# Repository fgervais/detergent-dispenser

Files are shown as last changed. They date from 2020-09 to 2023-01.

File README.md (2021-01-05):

# Detergent Dispenser

HE laundry detergent is quite concentrated and front loading washing machines
use really little water. With those two factors put together, it's really easy
to put too much detergent and so soap will be left even after the rinse cycle.

This project aim to automate the dispensing of a precise amount of detergent.

## Board

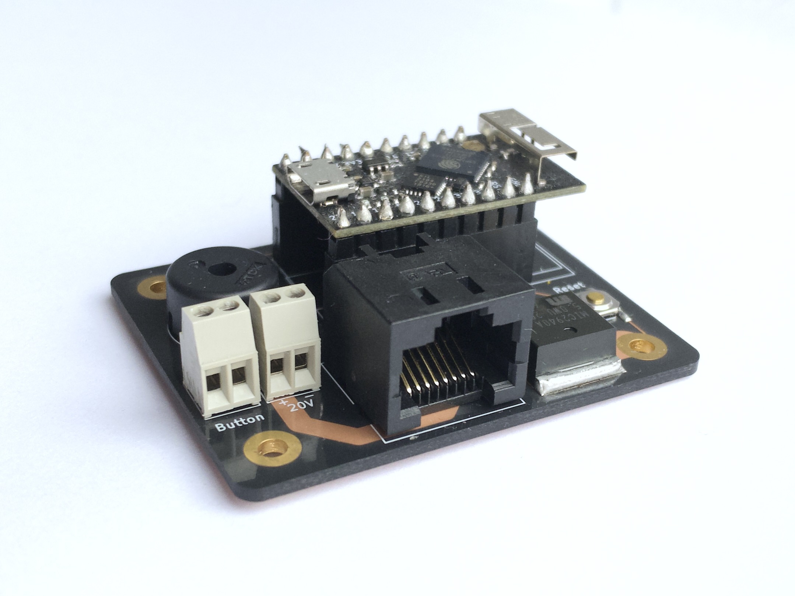
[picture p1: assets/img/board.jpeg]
Motherboard


## Assembled Unit

After holding the button for 1 seconds, the pump will dispense 7.5ml of
detergent. This has been empirically determined to be the required amount
for a small load on our dishwasher using our usual soap.

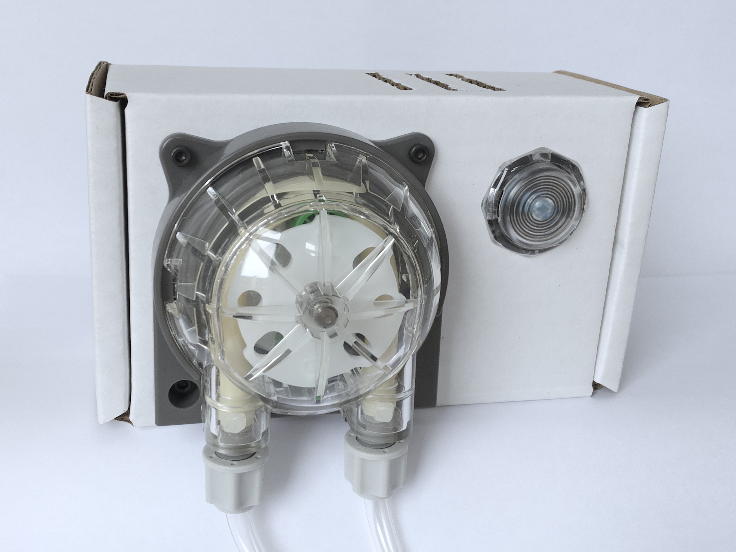
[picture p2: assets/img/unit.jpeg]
Assembled


## Installed

The pump feeds directly from the bottle.

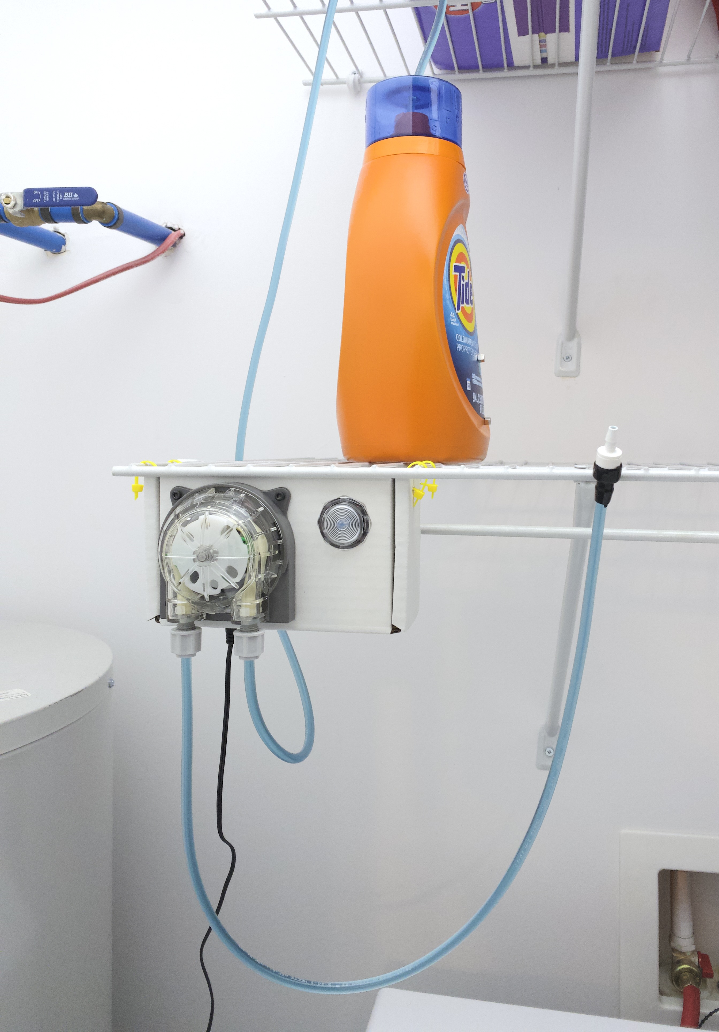
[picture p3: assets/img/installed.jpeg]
Installed


### Resource Efficiency

The bottle in this picture is rated for 44 loads but with the proper quantity determined for our specific case along with precise dispensing, we will get over 250 loads from this bottle.

(272 small loads of 7.5ml)

## Control App (Blynk)

The app shows when a dispense occurred and keep a global count since last
manual reset. It is also possible to start a dispense from the app.

All controls are locked by default and need to get unlocked through the
lock/unlock button. Once unlocked, only a single action is allowed before
controls are locked again automatically. This is to prevent unwanted counter reset or dispense.

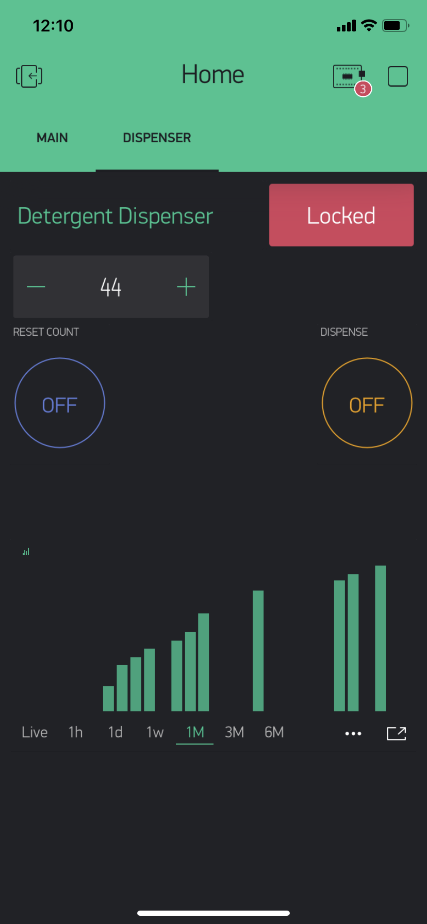
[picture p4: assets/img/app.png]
Blynk Project


## Next Steps

A couple improvements could be done to this project.

1. The output of the dispenser could be permanently mounted to the washing
machine soap compartment.

2. In normal mode, the esp32 uses quite a lot of power and this translates to
a power regulator hovering just under 70C in normal operation. As the device
does nothing most of the time, power management could be added so the regulator
doesn't have to dissipate that much power.

3. The ground/power doesn't seem to be so stable on the board as touching the
pins can sometime trigger a button press or a glitch on the pump sync signal.
This doesn't seem to be too much of an issue when the device is assembled in
the case.

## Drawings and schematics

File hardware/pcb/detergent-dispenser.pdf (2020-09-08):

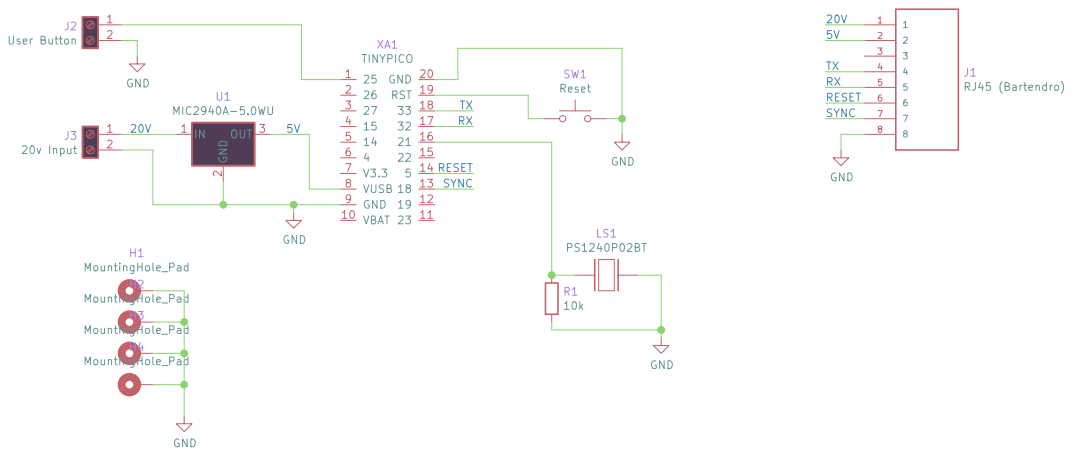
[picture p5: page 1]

File: detergent-dispenser.sch Sheet: /
Id: 1/1 Title:

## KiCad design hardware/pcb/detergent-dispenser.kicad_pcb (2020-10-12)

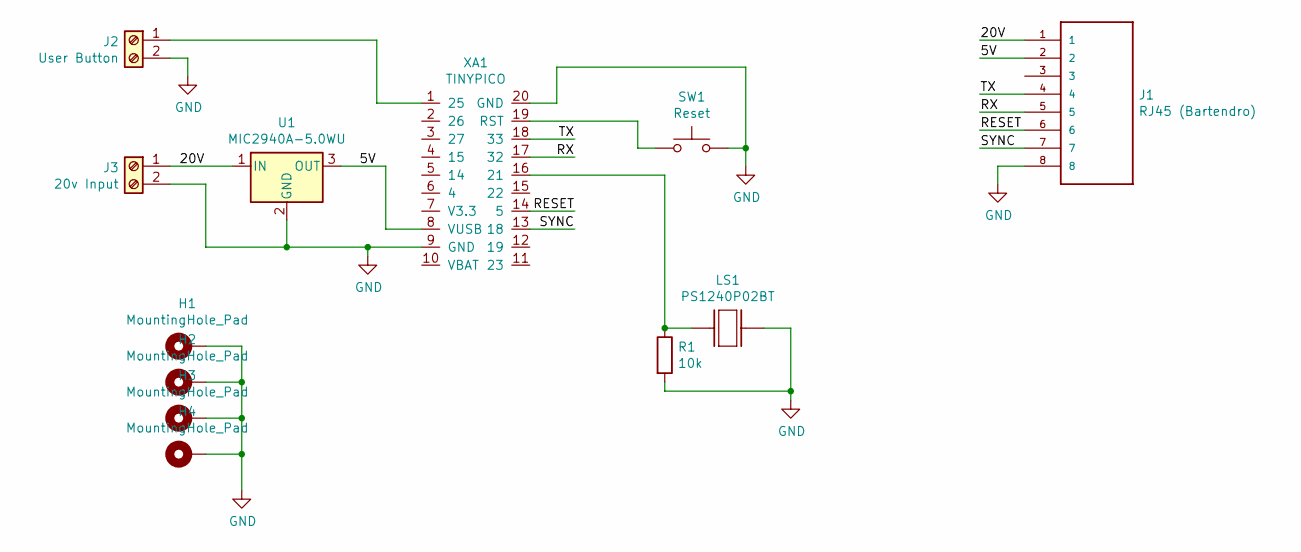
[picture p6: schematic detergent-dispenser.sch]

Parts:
H1, H2, H3, H4: MountingHole_Pad; MountingHole_2.7mm_M2.5_Pad
J1: RJ45 (Bartendro); AMPHENOL_RJHSE-5080
J2: User Button; TE_1546215-2
J3: 20v Input; TE_1546215-2
LS1: PS1240P02BT; XDCR_PS1240P02BT
R1: 10k; C_0603_1608Metric_Pad1.05x0.95mm_HandSolder
SW1: Reset; SW_SPST_TL3342
U1: MIC2940A-5.0WU; TO-263-3_TabPin2
XA1: TINYPICO

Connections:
/5V: J1.2, U1.3 (OUT), XA1.8 (VUSB)
/20V: J1.1, J3.1, U1.1 (IN)
/RESET: J1.6, XA1.14 (5)
/RX: J1.5, XA1.17 (32)
/SYNC: J1.7, XA1.13 (18)
/TX: J1.4, XA1.18 (33)
GND: H1.1, H2.1, H3.1, H4.1, J1.8, J2.2, J3.2, LS1.2, R1.2, SW1.2, U1.2 (GND), XA1.9 (GND), XA1.20 (GND)
unnamed: J2.1, XA1.1 (25)
unnamed: LS1.1, R1.1, XA1.16 (21)
unnamed: SW1.1, XA1.19 (RST)

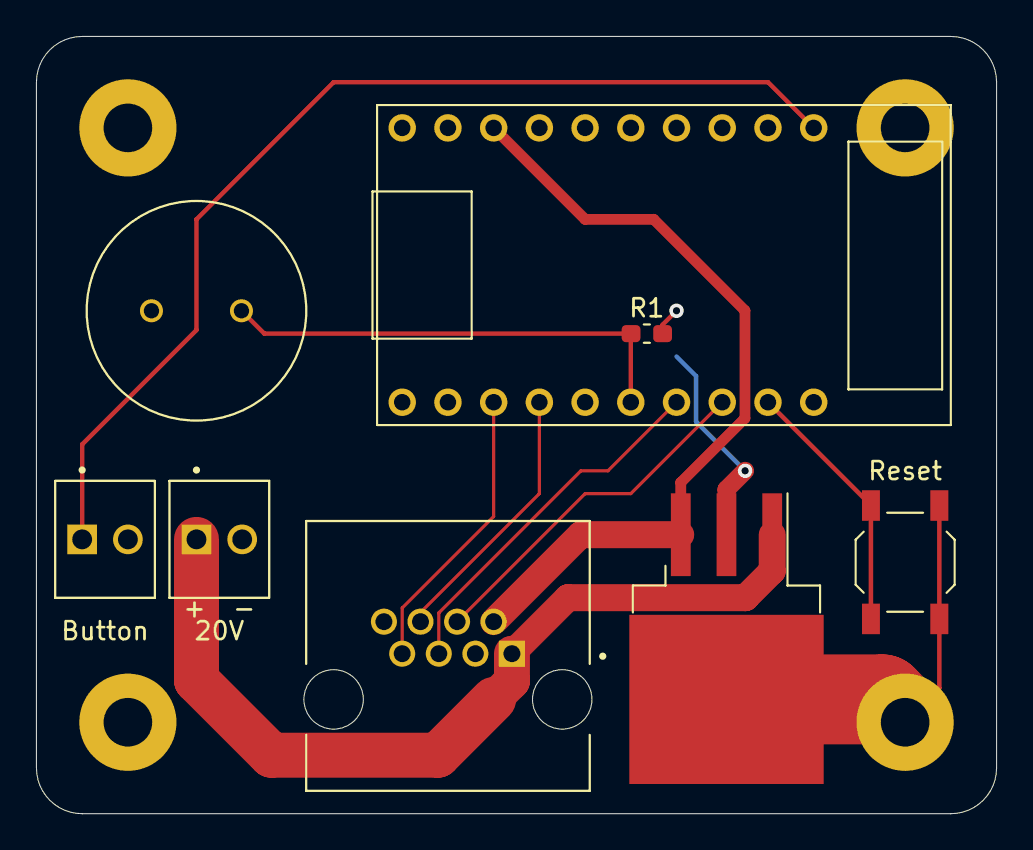
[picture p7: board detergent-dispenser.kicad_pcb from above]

Board: 2 copper layers, 53.3 x 43.2 mm, 12 parts (0 on the bottom side), 10 nets.

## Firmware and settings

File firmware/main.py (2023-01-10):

import network
import time
import tinypico as TinyPICO
import micropython
import esp32
import machine
import secret

from machine import Pin, PWM, ADC, TouchPad, RTC, UART


BUZZER_PIN = 21
BUTTON_PIN = 25
UART_RX_PIN = 32
UART_TX_PIN = 33
RESET_PIN = 5
SYNC_PIN = 18


wlan = network.WLAN(network.STA_IF)
wlan.active(True)
if not wlan.isconnected():
    print("connecting to network...")
    wlan.connect(secret.ESSID, secret.PSK)
    while not wlan.isconnected():
        time.sleep(1)
print("network config:", wlan.ifconfig())


class Button:
    def __init__(self, pin, callback):
        self.pin = pin
        self.callback = callback

        self.enable()

    def _callback(self, pin):
        self.disable()
        self.callback(pin)

    def disable(self):
        self.pin.irq(trigger=0, handler=None)
        self._enabled = False

    def enable(self):
        self.pin.irq(trigger=Pin.IRQ_FALLING, handler=self._callback)
        self._enabled = True

    @property
    def pressed(self):
        return not self.pin.value()

    @property
    def long_pressed(self):
        time.sleep(0.5)

        for i in range(5):
            time.sleep(0.1)
            if not self.pressed:
                return False

        return True

    @property
    def enabled(self):
        return self._enabled


class Buzzer:
    def __init__(self, pwm_pin):
        self.pwm_pin = pwm_pin

    def beep(self):
        self.pwm_pin.duty(512)
        time.sleep(0.05)
        self.pwm_pin.duty(0)

    def beeps(self, number):
        for i in range(number):
            self.beep()
            time.sleep(0.05)


class Bartendro:
    def __init__(self, uart, buzzer, button, reset_pin, sync_pin):
        self.uart = uart
        self.buzzer = buzzer
        self.button = button

        self.dispense_required = False
        self.last_dispense_ticks = None
        self.button_enable_delay_ms = 1000

        self.reset = Pin(reset_pin, Pin.OUT, value=1)
        # Ensure that the Bartendro has time to reset (high min. 1ms)
        time.sleep(0.1)
        self.reset.value(0)

        time.sleep(0.5)

        # self.sync = PWM(Pin(sync_pin), freq=500, duty=512)

        print("Waiting for dispenser")
        self.enter_text_mode()
        print("Bartendro ready!")

    def read(self):
        data = uart.read()
        for i in range(5):
            print("Reading (" + str(i) + "):")
            print(data)
            if data:
                break
            time.sleep(0.1)

        return data

    def enter_text_mode(self):
        while True:
            # In case the TinyPICO is reset, the Bartendro will already be
            # in text mode.
            prompt = self.read()
            if prompt == b"\r\nParty Robotics Dispenser at your service!\r\n\r\n>":
                break

            # Send text mode magic
            uart.write("!!!")
            time.sleep(2)

        # uart.write("led_idle\r")

    def dispense(self):
        if not self.dispense_required:
            self.dispense_required = True
            self.buzzer.beep()

    def run(self):
        if self.dispense_required:
            if self.button.long_pressed:
                # 50 200 => 7.5ml
                # 0.150ml per tick
                # 66 200 => 10ml
                #
                # 83 200 => 12.45ml (seems more like 11ml)
                uart.write("tickdisp 50 200\r")

                self.last_dispense_ticks = time.ticks_ms()
            else:
                self.buzzer.beeps(3)
                self.button.enable()

            self.dispense_required = False
        # Add a little delay after the dispense so the button release
        # bounces are not registered as a new dispense request
        elif not self.button.enabled and (
            time.ticks_diff(time.ticks_ms(), self.last_dispense_ticks)
            > self.button_enable_delay_ms
        ):
            self.button.enable()


buzzer = Buzzer(PWM(Pin(BUZZER_PIN), freq=4000, duty=0))
buzzer.beep()

uart = UART(1, baudrate=9600, tx=UART_TX_PIN, rx=UART_RX_PIN)

button = Button(
    Pin(BUTTON_PIN, Pin.IN, Pin.PULL_UP), callback=lambda pin: dispenser.dispense()
)

dispenser = Bartendro(uart, buzzer, button, RESET_PIN, SYNC_PIN)


while True:
    dispenser.run()

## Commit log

2020-09-07 PCB rev 0
    [detergent-dispenser.kicad_pcb, detergent-dispenser.sch]
2020-09-08 Export rev 0 schematic as pdf
2020-09-08 Got the Bartendro reset and sync pin going
    [main.py]
2020-10-12 Send the pump discovery token and add button
2020-10-12 Add a note to PCB about 5v protection
    [detergent-dispenser.kicad_pcb]
2020-10-13 Add button IRQ
2020-10-13 Print help on button press
2020-11-19 Set led_done on button press
2020-11-21 Dispense outside of interrupt context
2020-11-23 Add control over a blynk button
2020-12-13 Add lock button handling
2020-12-13 Pump only a little
2020-12-21 Do not use leds
2020-12-21 Add buzzer on button press
    [main.py]
2020-12-21 Increase the dispense count correctly
    [main.py]
2021-01-02 Need to hold the button to dispense
2021-01-03 Add the assembled unit image
2021-01-04 Update board image
2021-01-06 Add a Buzzer class
    [main.py]
2021-01-06 Set button as a Bartendro class member
2021-01-09 Fix ticks_diff from time module
    [main.py]
2021-01-09 Set dispense amount to 7.5 ml
